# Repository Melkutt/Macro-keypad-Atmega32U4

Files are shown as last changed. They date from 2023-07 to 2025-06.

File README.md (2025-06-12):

This is still in progress, as usual, but it works.



Macro keypad based of a AtMega32U4AU, SK6812 backlit and Cherry key's



--------------------------------------------------------------
20250612:
I have updated the PCB now in KiCad 9 to work out a few buggs.
--------------------------------------------------------------

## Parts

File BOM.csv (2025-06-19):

Reference | Qty | Value | DNP | Exclude from BOM | Exclude from Board | Footprint | Datasheet
C1,C2 | 2 | 22p |  |  |  | Capacitor_SMD:C_0603_1608Metric_Pad1.08x0.95mm_HandSolder | ~
C3,C20 | 2 | 1u |  |  |  | Capacitor_SMD:C_0603_1608Metric_Pad1.08x0.95mm_HandSolder | ~
C4,C5,C6,C7,C8,C9,C10,C11,C12,C13,C14,C15,C16,C17,C18,C21,C22,C23 | 18 | 100n |  |  |  | Capacitor_SMD:C_0603_1608Metric_Pad1.08x0.95mm_HandSolder | ~
C19,C27 | 2 | 10u |  |  |  | Capacitor_SMD:C_0603_1608Metric_Pad1.08x0.95mm_HandSolder | ~
C24,C25 | 2 | 10n |  |  |  | Capacitor_SMD:C_0603_1608Metric_Pad1.08x0.95mm_HandSolder | ~
C26 | 1 | 1n |  |  |  | Capacitor_SMD:C_0603_1608Metric_Pad1.08x0.95mm_HandSolder | ~
D1,D2,D3,D4,D5,D6,D7,D8,D9,D10,D11,D12,D13,D14,D15 | 15 | LL4448 |  |  |  | Diode_SMD:D_MiniMELF | http://www.vishay.com/docs/85557/ll4148.pdf
D16,D17,D18,D19,D20,D21,D22,D23,D24,D25,D26,D27,D28,D29,D30 | 15 | SK6812MINI |  |  |  | LED_SMD:LED_SK6812MINI_PLCC4_3.5x3.5mm_P1.75mm | https://cdn-shop.adafruit.com/product-files/2686/SK6812MINI_REV.01-1-2.pdf
D31 | 1 | LED |  |  |  | LED_SMD:LED_0603_1608Metric_Pad1.05x0.95mm_HandSolder | ~
F1 | 1 | Fuse |  |  |  | Fuse:Fuse_1206_3216Metric_Pad1.42x1.75mm_HandSolder | ~
FB1 | 1 | FerriteBead_Small |  |  |  | Inductor_SMD:L_0603_1608Metric_Pad1.05x0.95mm_HandSolder | ~
H1,H2,H3,H4 | 4 | MountingHole |  |  |  | MountingHole:MountingHole_4.3mm_M4 | ~
J1 | 1 | JTAG |  |  |  | Connector_PinSocket_2.54mm:PinSocket_2x03_P2.54mm_Vertical | ~
J2 | 1 | USB_C_Receptacle |  |  |  | Connector_USB:USB_C_Receptacle_GCT_USB4085 | https://www.usb.org/sites/default/files/documents/usb_type-c.zip
R1,R2 | 2 | 22 |  |  |  | Resistor_SMD:R_0603_1608Metric_Pad0.98x0.95mm_HandSolder | ~
R3,R4,R5,R6,R7 | 5 | R |  |  |  | Resistor_SMD:R_0603_1608Metric_Pad0.98x0.95mm_HandSolder | ~
R8,R9 | 2 | 470 |  |  |  | Resistor_SMD:R_0603_1608Metric_Pad0.98x0.95mm_HandSolder | ~
R10 | 1 | 10k |  |  |  | Resistor_SMD:R_0603_1608Metric_Pad0.98x0.95mm_HandSolder | ~
R11,R12 | 2 | 5k1 |  |  |  | Resistor_SMD:R_0603_1608Metric_Pad0.98x0.95mm_HandSolder | ~
R13 | 1 | 560R |  |  |  | Resistor_SMD:R_0603_1608Metric_Pad0.98x0.95mm_HandSolder | ~
SW1,SW2,SW3,SW4,SW5,SW6,SW7,SW8,SW9,SW10,SW11,SW12,SW13,SW14,SW15 | 15 | SW_Push |  |  |  | PCM_Switch_Keyboard_Cherry_MX:SW_Cherry_MX_PCB_1.00u | ~
SW17 | 1 | SW_DIP_x01 |  |  |  | Button_Switch_SMD:SW_Push_1P1T_NO_CK_KSC7xxJ | ~
U1 | 1 | ATmega32U4-M |  |  |  | Package_QFP:TQFP-44_10x10mm_P0.8mm | http://ww1.microchip.com/downloads/en/DeviceDoc/Atmel-7766-8-bit-AVR-ATmega16U4-32U4_Datasheet.pdf
U2 | 1 | USBLC6-2SC6 |  |  |  | Package_TO_SOT_SMD:SOT-23-6 | https://www.st.com/resource/en/datasheet/usblc6-2.pdf
Y1 | 1 | TSX-3225 16.0000MF18X-B0 |  |  |  | Crystal:Crystal_SMD_SeikoEpson_TSX3225-4Pin_3.2x2.5mm | ~

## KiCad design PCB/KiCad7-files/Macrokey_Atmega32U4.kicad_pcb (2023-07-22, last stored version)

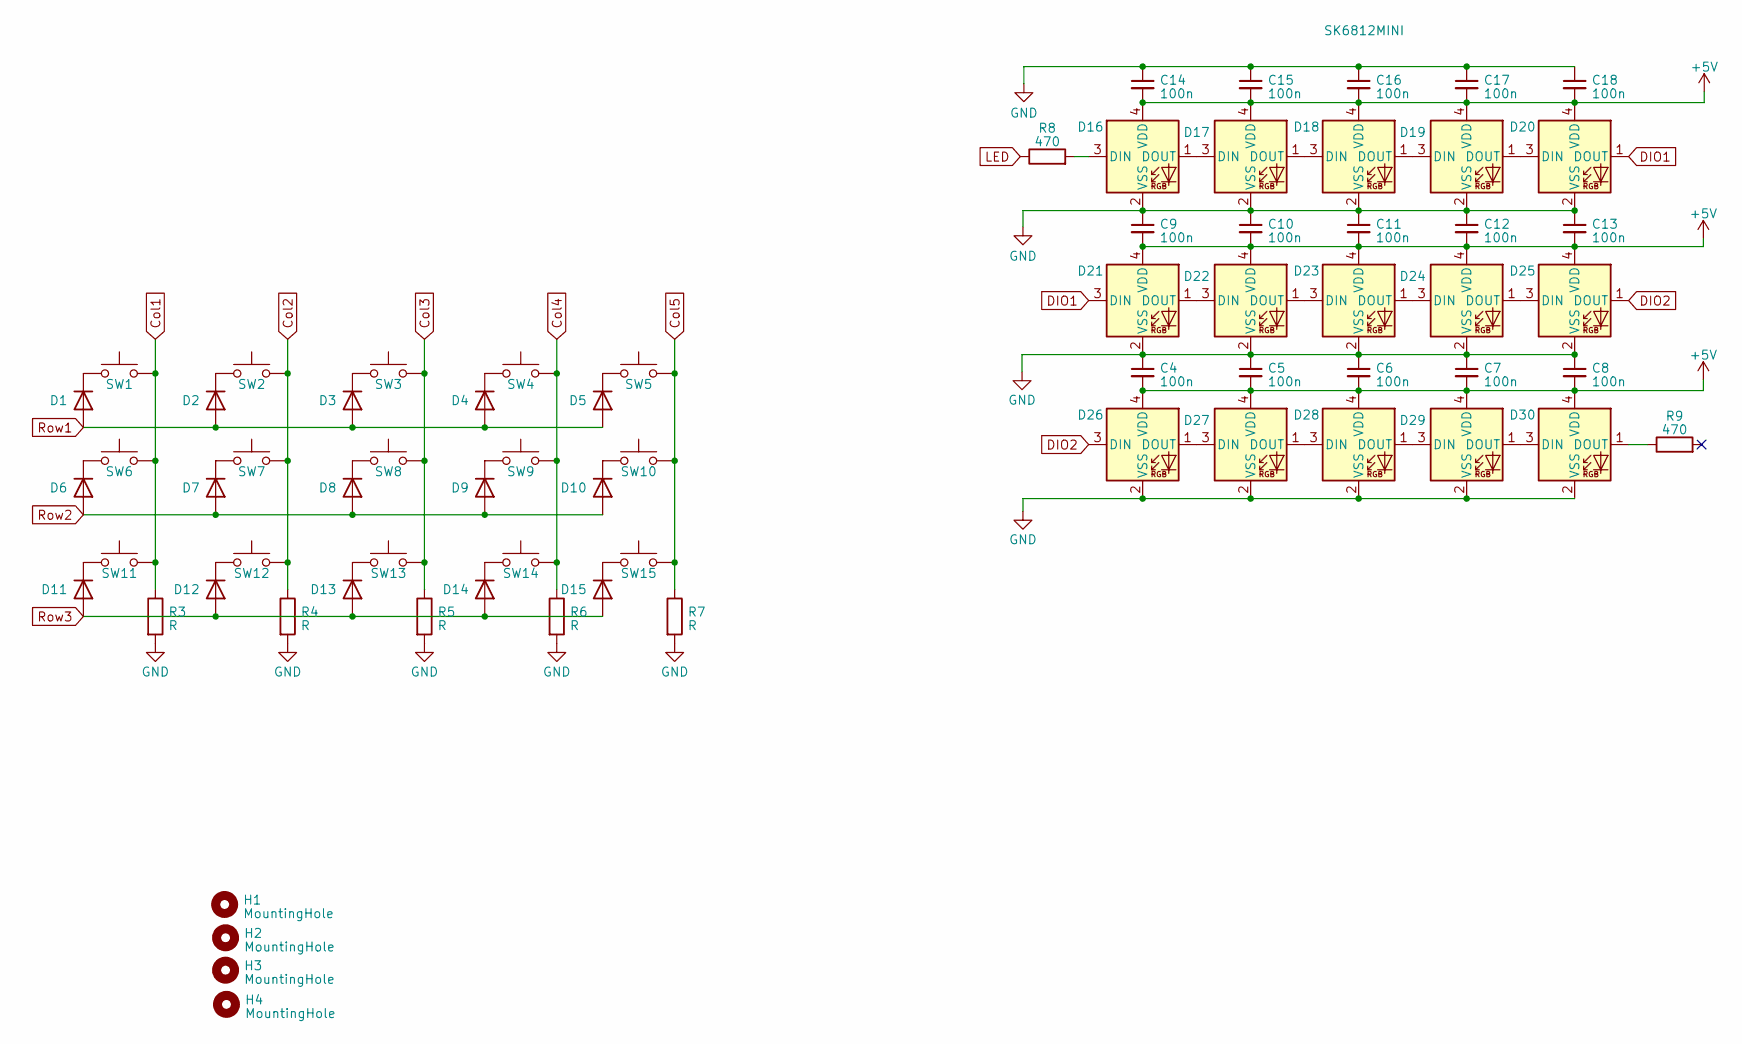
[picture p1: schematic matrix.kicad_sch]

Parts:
C4, C5, C6, C7, C8, C9, C10, C11, C12, C13, C14, C15, C16, C17, C18: 100n; C_0603_1608Metric_Pad1.08x0.95mm_HandSolder
D1, D2, D3, D4, D5, D6, D7, D8, D9, D10, D11, D12, D13, D14, D15: LL4448; D_MiniMELF
D16, D17, D18, D19, D20, D21, D22, D23, D24, D25, D26, D27, D28, D29, D30: SK6812MINI; LED_SK6812MINI_PLCC4_3.5x3.5mm_P1.75mm
H1, H2, H3, H4: MountingHole; MountingHole_4.3mm_M4
R3, R4, R5, R6, R7: R; R_0603_1608Metric_Pad0.98x0.95mm_HandSolder
R8, R9: 470; R_0603_1608Metric_Pad0.98x0.95mm_HandSolder
SW1, SW2, SW3, SW4, SW5, SW6, SW7, SW8, SW9, SW10, SW11, SW12, SW13, SW14, SW15: SW_Push; SW_Cherry_MX_PCB_1.00u

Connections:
+5V: C4.2, C5.2, C6.2, C7.2, C8.2, C9.2, C10.2, C11.2, C12.2, C13.2, C14.2, C15.2, C16.2, C17.2, C18.2, D16.4 (VDD), D17.4 (VDD), D18.4 (VDD), D19.4 (VDD), D20.4 (VDD), D21.4 (VDD), D22.4 (VDD), D23.4 (VDD), D24.4 (VDD), D25.4 (VDD), D26.4 (VDD), D27.4 (VDD), D28.4 (VDD), D29.4 (VDD), D30.4 (VDD); also elsewhere on the board
Col1: R3.1, SW1.2, SW6.2, SW11.2; also elsewhere on the board
Col2: R4.1, SW2.2, SW7.2, SW12.2; also elsewhere on the board
Col3: R5.1, SW3.2, SW8.2, SW13.2; also elsewhere on the board
Col4: R6.1, SW4.2, SW9.2, SW14.2; also elsewhere on the board
Col5: R7.1, SW5.2, SW10.2, SW15.2; also elsewhere on the board
DIO1: D20.1 (DOUT), D21.3 (DIN)
DIO2: D25.1 (DOUT), D26.3 (DIN)
GND: C4.1, C5.1, C6.1, C7.1, C8.1, C9.1, C10.1, C11.1, C12.1, C13.1, C14.1, C15.1, C16.1, C17.1, C18.1, D16.2 (VSS), D17.2 (VSS), D18.2 (VSS), D19.2 (VSS), D20.2 (VSS), D21.2 (VSS), D22.2 (VSS), D23.2 (VSS), D24.2 (VSS), D25.2 (VSS), D26.2 (VSS), D27.2 (VSS), D28.2 (VSS), D29.2 (VSS), D30.2 (VSS), R3.2, R4.2, R5.2, R6.2, R7.2; also elsewhere on the board
LED: R8.1; also elsewhere on the board
unnamed: D1.1 (K), SW1.1
unnamed: D2.1 (K), SW2.1
unnamed: D3.1 (K), SW3.1
unnamed: D4.1 (K), SW4.1
unnamed: D5.1 (K), SW5.1
unnamed: D6.1 (K), SW6.1
unnamed: D7.1 (K), SW7.1
unnamed: D8.1 (K), SW8.1
unnamed: D9.1 (K), SW9.1
unnamed: D10.1 (K), SW10.1
unnamed: D11.1 (K), SW11.1
unnamed: D12.1 (K), SW12.1
unnamed: D13.1 (K), SW13.1
unnamed: D14.1 (K), SW14.1
unnamed: D15.1 (K), SW15.1
unnamed: D16.3 (DIN), R8.2
unnamed: D16.1 (DOUT), D17.3 (DIN)
unnamed: D17.1 (DOUT), D18.3 (DIN)
unnamed: D18.1 (DOUT), D19.3 (DIN)
unnamed: D19.1 (DOUT), D20.3 (DIN)
unnamed: D21.1 (DOUT), D22.3 (DIN)
unnamed: D22.1 (DOUT), D23.3 (DIN)
unnamed: D23.1 (DOUT), D24.3 (DIN)
unnamed: D24.1 (DOUT), D25.3 (DIN)
unnamed: D26.1 (DOUT), D27.3 (DIN)
unnamed: D27.1 (DOUT), D28.3 (DIN)
unnamed: D28.1 (DOUT), D29.3 (DIN)
unnamed: D29.1 (DOUT), D30.3 (DIN)
unnamed: D30.1 (DOUT), R9.1
Row1: D1.2 (A), D2.2 (A), D3.2 (A), D4.2 (A), D5.2 (A); also elsewhere on the board
Row2: D6.2 (A), D7.2 (A), D8.2 (A), D9.2 (A), D10.2 (A); also elsewhere on the board
Row3: D11.2 (A), D12.2 (A), D13.2 (A), D14.2 (A), D15.2 (A); also elsewhere on the board

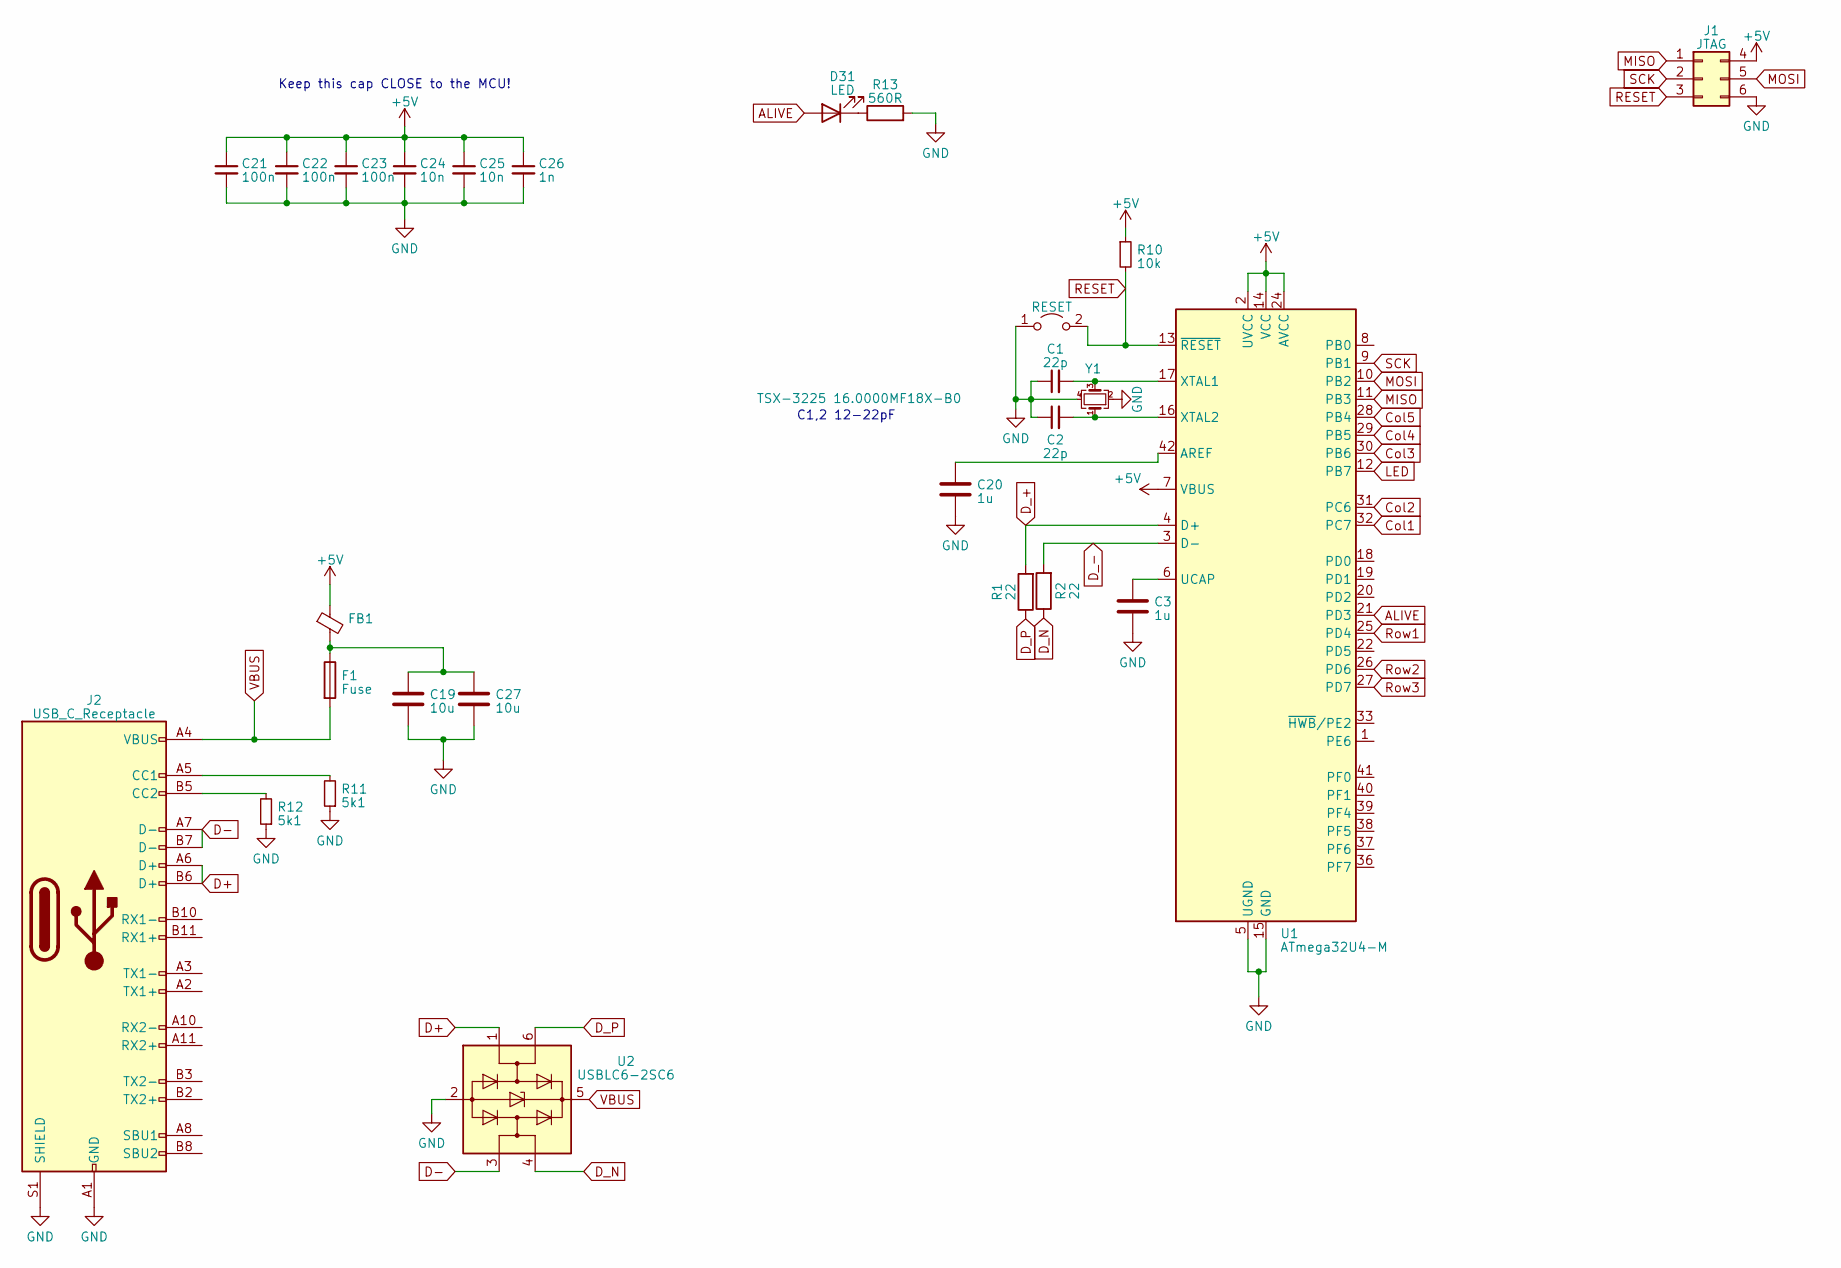
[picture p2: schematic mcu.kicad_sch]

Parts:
C1, C2: 22p; C_0603_1608Metric_Pad1.08x0.95mm_HandSolder
C3, C20: 1u; C_0603_1608Metric_Pad1.08x0.95mm_HandSolder
C19, C27: 10u; C_0603_1608Metric_Pad1.08x0.95mm_HandSolder
C21, C22, C23: 100n; C_0603_1608Metric_Pad1.08x0.95mm_HandSolder
C24, C25: 10n; C_0603_1608Metric_Pad1.08x0.95mm_HandSolder
C26: 1n; C_0603_1608Metric_Pad1.08x0.95mm_HandSolder
D31: LED; LED_0603_1608Metric_Pad1.05x0.95mm_HandSolder
F1: Fuse; Fuse_1206_3216Metric_Pad1.42x1.75mm_HandSolder
FB1: FerriteBead_Small; L_0603_1608Metric_Pad1.05x0.95mm_HandSolder
J1: JTAG; PinSocket_2x03_P2.54mm_Vertical
J2: USB_C_Receptacle; USB_C_Receptacle_GCT_USB4085
JP1: RESET; SolderJumper-2_P1.3mm_Open_TrianglePad1.0x1.5mm
R1, R2: 22; R_0603_1608Metric_Pad0.98x0.95mm_HandSolder
R10: 10k; R_0603_1608Metric_Pad0.98x0.95mm_HandSolder
R11, R12: 5k1; R_0603_1608Metric_Pad0.98x0.95mm_HandSolder
R13: 560R; R_0603_1608Metric_Pad0.98x0.95mm_HandSolder
U1: ATmega32U4-M; TQFP-44_10x10mm_P0.8mm
U2: USBLC6-2SC6; SOT-23-6
Y1: TSX-3225 16.0000MF18X-B0; Crystal_SMD_SeikoEpson_TSX3225-4Pin_3.2x2.5mm

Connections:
+5V: C21.1, C22.1, C23.1, C24.1, C25.1, C26.1, FB1.1, J1.4, R10.1, U1.2 (UVCC), U1.7 (VBUS), U1.14 (VCC), U1.24 (AVCC), U1.34 (VCC), U1.44 (AVCC); also elsewhere on the board
ALIVE: D31.2 (A), U1.21 (PD3)
Col1: U1.32 (PC7); also elsewhere on the board
Col2: U1.31 (PC6); also elsewhere on the board
Col3: U1.30 (PB6); also elsewhere on the board
Col4: U1.29 (PB5); also elsewhere on the board
Col5: U1.28 (PB4); also elsewhere on the board
D+: J2.A6 (D+), J2.B6 (D+), U2.1 (I/O1)
D-: J2.A7 (D-), J2.B7 (D-), U2.3 (I/O2)
D_+: R1.2, U1.4 (D+)
D_-: R2.2, U1.3 (D-)
D_N: R2.1, U2.4 (I/O2)
D_P: R1.1, U2.6 (I/O1)
GND: C1.1, C2.1, C3.2, C19.1, C20.2, C21.2, C22.2, C23.2, C24.2, C25.2, C26.2, C27.1, J1.6, J2.A1 (GND), J2.A12 (GND), J2.B1 (GND), J2.B12 (GND), J2.S1 (SHIELD), JP1.1 (A), R11.1, R12.1, R13.2, U1.5 (UGND), U1.15 (GND), U1.23 (GND), U1.35 (GND), U1.43 (GND), U1.45 (GND), U2.2 (GND), Y1.2, Y1.4; also elsewhere on the board
LED: U1.12 (PB7); also elsewhere on the board
MISO: J1.1, U1.11 (PB3)
MOSI: J1.5, U1.10 (PB2)
unnamed: C19.2, C27.2, F1.1, FB1.2
unnamed: D31.1 (K), R13.1
unnamed: J2.A5 (CC1), R11.2
unnamed: J2.B5 (CC2), R12.2
unnamed: C20.1, U1.42 (AREF)
unnamed: C3.1, U1.6 (UCAP)
unnamed: C1.2, U1.17 (XTAL1), Y1.3
unnamed: C2.2, U1.16 (XTAL2), Y1.1
RESET: J1.3, JP1.2 (B), R10.2, U1.13 (~RESET)
Row1: U1.25 (PD4); also elsewhere on the board
Row2: U1.26 (PD6); also elsewhere on the board
Row3: U1.27 (PD7); also elsewhere on the board
SCK: J1.2, U1.9 (PB1)
VBUS: F1.2, J2.A4 (VBUS), J2.A9 (VBUS), J2.B4 (VBUS), J2.B9 (VBUS), U2.5 (VBUS)

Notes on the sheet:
Keep this cap CLOSE to the MCU!
C1,2 12-22pF

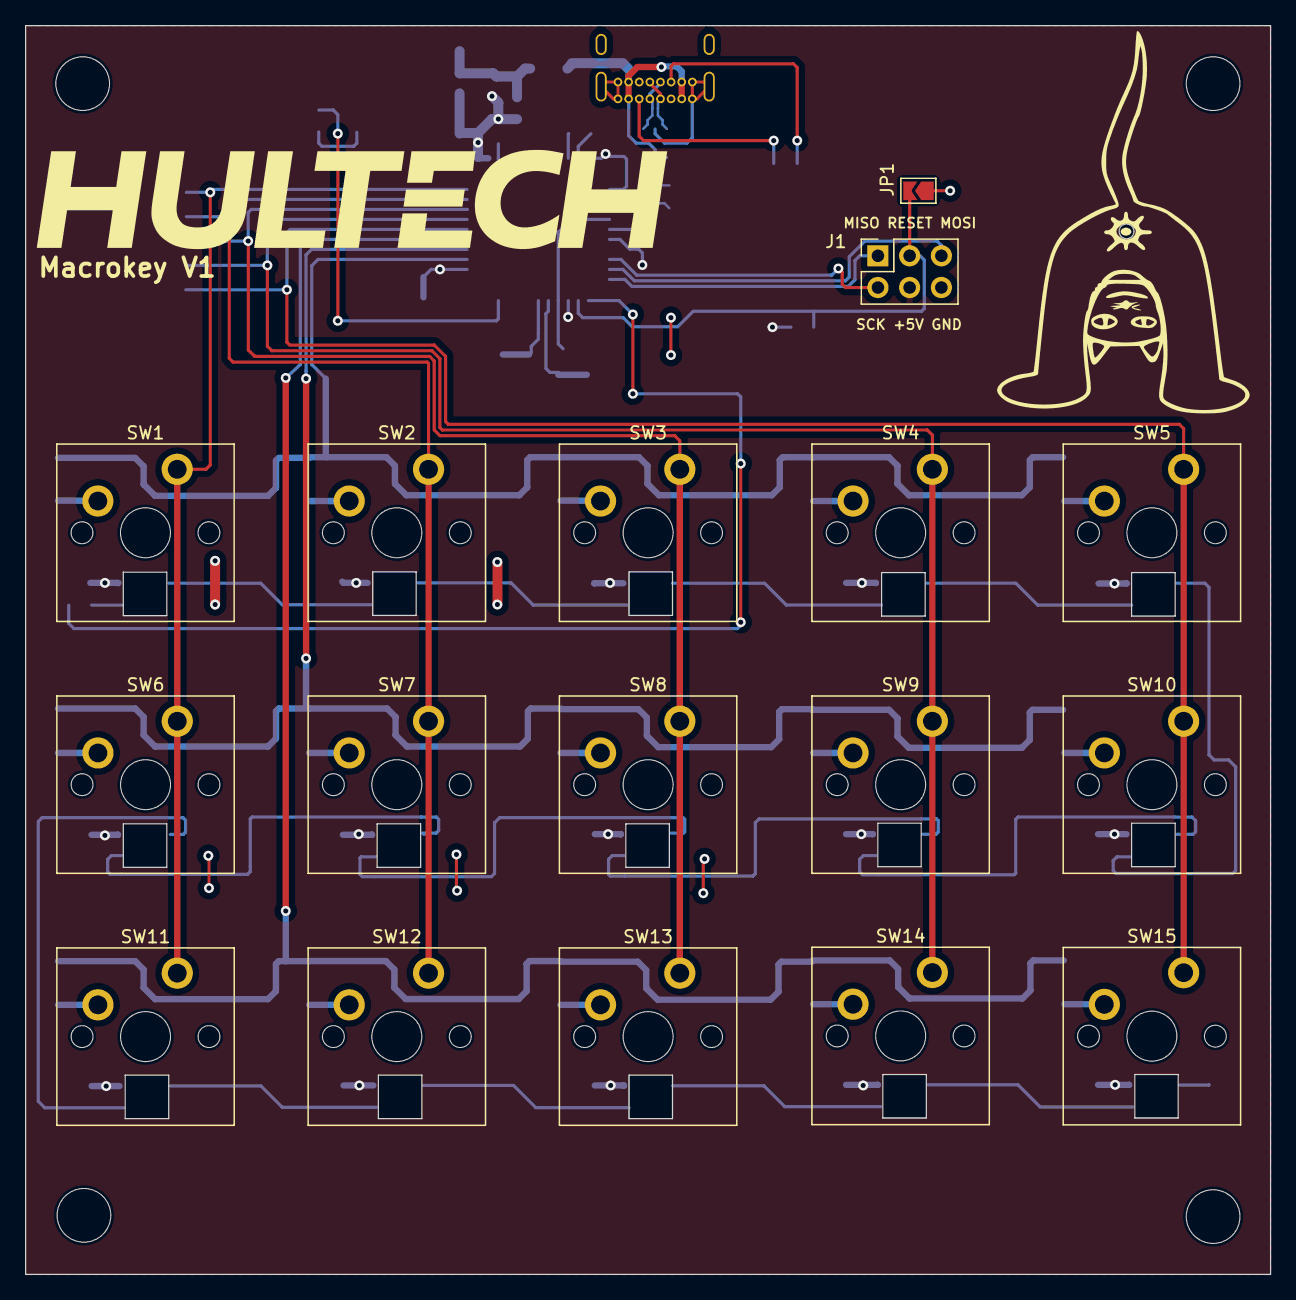
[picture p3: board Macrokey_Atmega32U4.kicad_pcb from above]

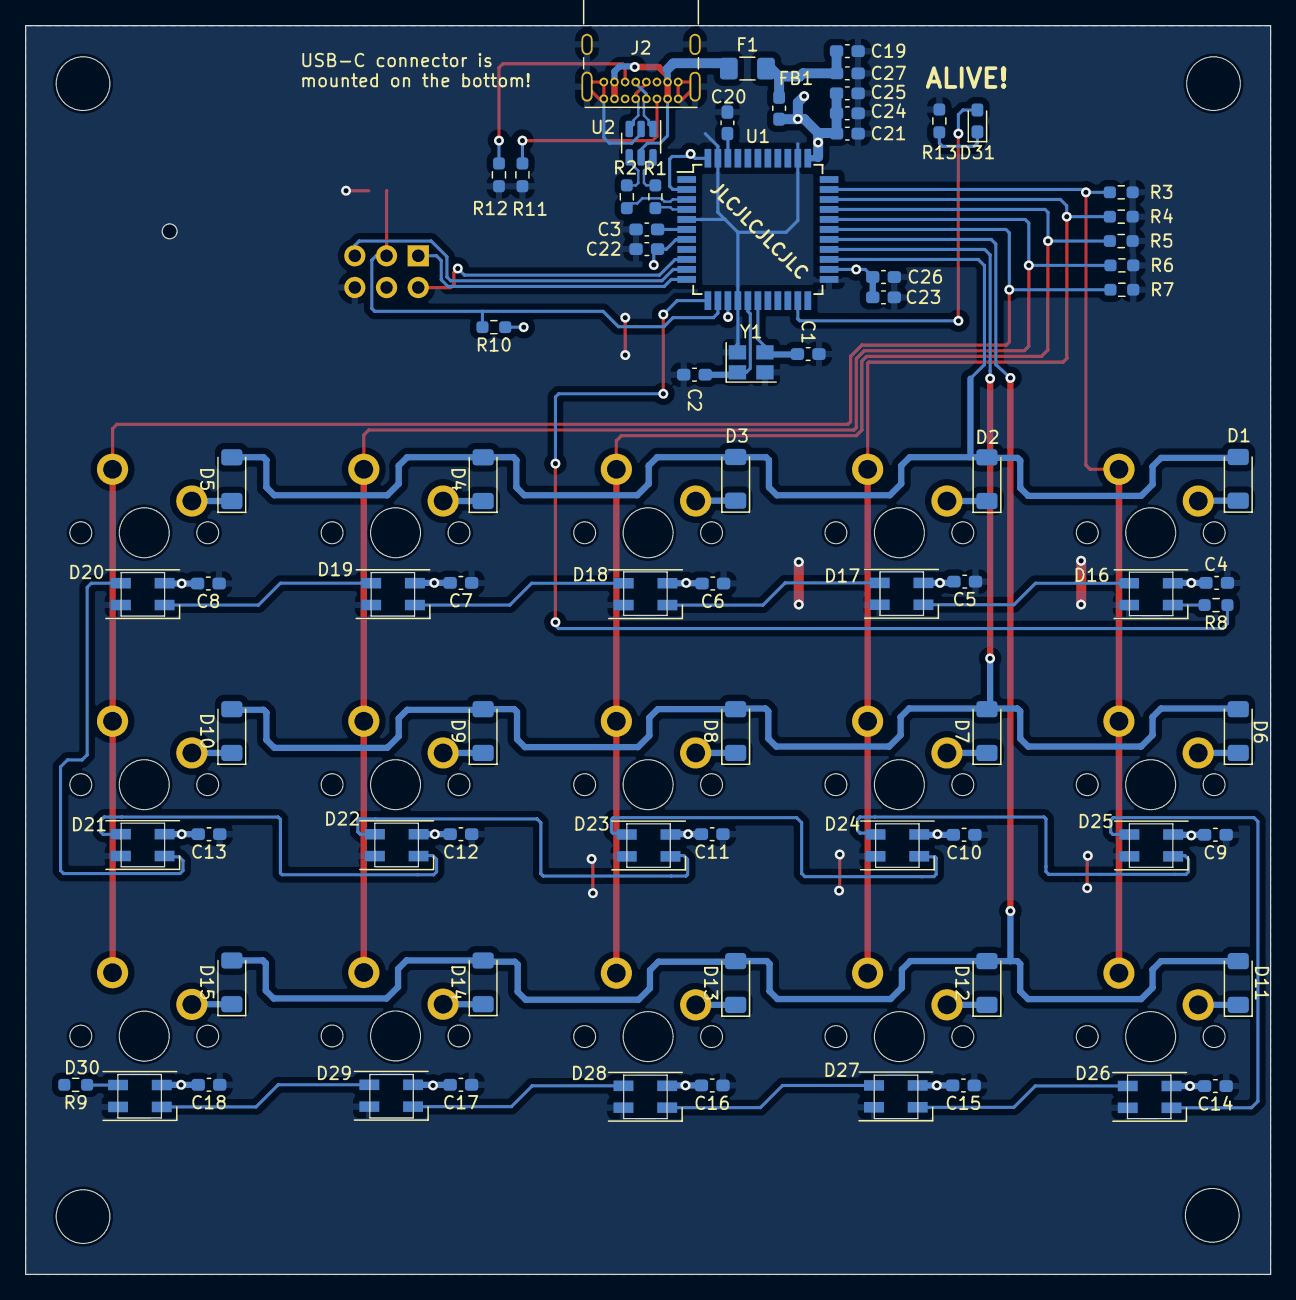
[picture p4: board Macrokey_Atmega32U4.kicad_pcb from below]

Board: 2 copper layers, 99.7 x 100.0 mm, 98 parts (77 on the bottom side), 62 nets.

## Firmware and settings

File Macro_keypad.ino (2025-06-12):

#include <Adafruit_NeoMatrix.h>
#include "Adafruit_Keypad.h"
#include "Keyboard.h"

#define PIN       11 //LED pin
#define NUMPIXELS 15
#define KEY_JUST_RELEASED (0) ///< key has been released
#define KEY_JUST_PRESSED (1)


const byte ROWS = 3; // rows
const byte COLS = 5; // columns

//define the symbols on the buttons of the keypads
char keys[ROWS][COLS] = {
  {'0','1','2','3','4'},
  {'5','6','7','8','9'},
  {'A','B','C','D','E'},
};

byte colPins[COLS] = {13, 5, 10, 9, 8}; //connect to the column pinouts of the keypad
byte rowPins[ROWS] = {4, 12, 6}; //connect to the row pinouts of the keypad


//initialize an instance of class NewKeypad
Adafruit_Keypad customKeypad = Adafruit_Keypad( makeKeymap(keys), rowPins, colPins, ROWS, COLS);

unsigned char randNumber;


Adafruit_NeoPixel pixels(NUMPIXELS, PIN, NEO_GRB + NEO_KHZ800);
#define DELAYVAL 30

void setup() {

  pinMode(4, INPUT_PULLUP);
  pinMode(6, INPUT_PULLUP);
  pinMode(12, INPUT_PULLUP);


  Serial.begin(115200);

  pixels.begin();
  randomSeed(analogRead(38));
  pixels.setBrightness(10);
  customKeypad.begin();
  Keyboard.begin();
  
}

void loop() {

  ledMatrix();

  customKeypad.tick();

  while(customKeypad.available()){
    keypadEvent e = customKeypad.read();
    Serial.println((char)e.bit.KEY);
    

    if(e.bit.EVENT == KEY_JUST_PRESSED);  
    
    char key = (char)e.bit.KEY;
    if(key=='0'){ 
    Keyboard.press('0');
    Keyboard.releaseAll();
    }
    if(key=='1'){ 
    Keyboard.press('1');   
    Keyboard.releaseAll();
    }
    if(key=='2'){ 
    Keyboard.press('2'); 
    Keyboard.releaseAll();
    }
    if(key=='3'){ 
    Keyboard.print('3'); 
    Keyboard.releaseAll();
    }
    if(key=='4'){ 
    Keyboard.press('4'); 
    Keyboard.releaseAll();
    }
    if(key=='5'){ 
    Keyboard.press('5'); 
    Keyboard.releaseAll();
    }
    if(key=='6'){ 
    Keyboard.press('6'); 
    Keyboard.releaseAll();
    }
    if(key=='7'){ 
    Keyboard.press('7'); 
    Keyboard.releaseAll();
    }
    if(key=='8'){ 
    Keyboard.press('8'); 
    Keyboard.releaseAll();
    }
    if(key=='9'){ 
    Keyboard.press('9'); 
    Keyboard.releaseAll();
    }
    if(key=='A'){ 
    Keyboard.press('A'); 
    Keyboard.releaseAll();
    }
    if(key=='B'){ 
    Keyboard.press('B'); 
    Keyboard.releaseAll();
    }    
    if(key=='C'){ 
    Keyboard.press('C'); 
    Keyboard.releaseAll();
    }
    if(key=='D'){ 
    Keyboard.press('D'); 
    Keyboard.releaseAll();
    } 
    if(key=='E'){ 
    Keyboard.press('E'); 
    Keyboard.releaseAll();
    }    

    delay(50);


    } 
  }

void ledMatrix() {

  for(int i=0; i<NUMPIXELS; i++) {
  for(int i=random(0, 15); i<NUMPIXELS; i++) {

    randNumber = random(0, 255); //To adjust the color span

    pixels.setPixelColor(i, pixels.Color(random(), random(), random())); //Random colors

    pixels.show();
    
    delay(DELAYVAL);

    return;

    }  
  }
}

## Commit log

2023-07-22 Add files via upload
    LED and key inputs works.
2025-06-12 Create KiCad_9
